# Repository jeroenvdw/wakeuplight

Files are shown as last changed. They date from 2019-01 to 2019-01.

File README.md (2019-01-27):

# Arduino Wake Up Light
## Features
 - a normal alarm (like any alarm clock)
 - a repeating alarm, which can be configured for every day of the week
 - it can function as a night lamp
 - choose the buzzer or any MP3 to wake up with
 - time is kept with a RTC (real time clock)
 - all settings (max light intensity, wake up duration, ...) can be configured within the menu
 - when power is switched off and on again, the date, time and other settings are restored

## Parts list
 - Arduino Uno
 - RTC (I used the DS3231 for a Raspberry Pi because of the small form factor)
 - LCD; 16x2 characters, with I²C interface
 - Buzzer
 - MP3 module (I used the DFRobot DFPlayer)
 - Speaker 
 - LED strtip (12 volt)
 - NPN Transistor (I used TIP-120)
 - 7 push buttons (for Left, Right, Up, Down, OK, Cancel, Snooze)
 - 9 resistors 1K Ohm (7 pull down resistors, one for the MP3 module, one for the transistor)
 - 12 Volt power supply
 - Wires, Male/Female headers, Perfboard, ... (to solder everything together)
 
 ## The build
 The schematic to solder everything together can be found in "schematic.pdf" (schematic.fzz is the original Fritzing file)
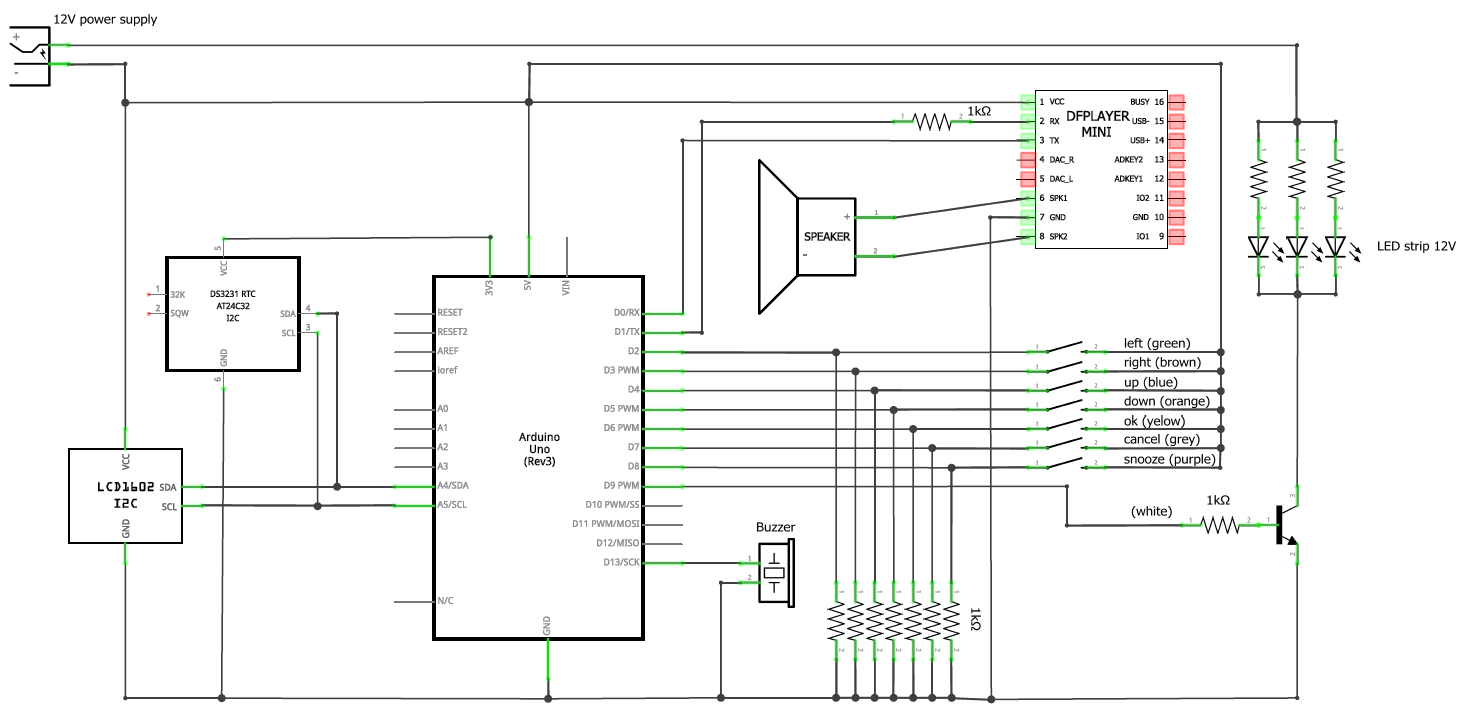
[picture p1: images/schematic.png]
 
 
 ## The code
 For a better understanding of the lifecycle of the alarm, have a look at "lifecycle.pdf". 
 To undesttand the menu structure, check out "screenflow.pdf" (source files are in the \*.dia files)
 
 All literals in the menu are now in Dutch. Rename the "Literals_EN.h" file to "Literals.h" to build the proejct using English literals.
 
 ## Images
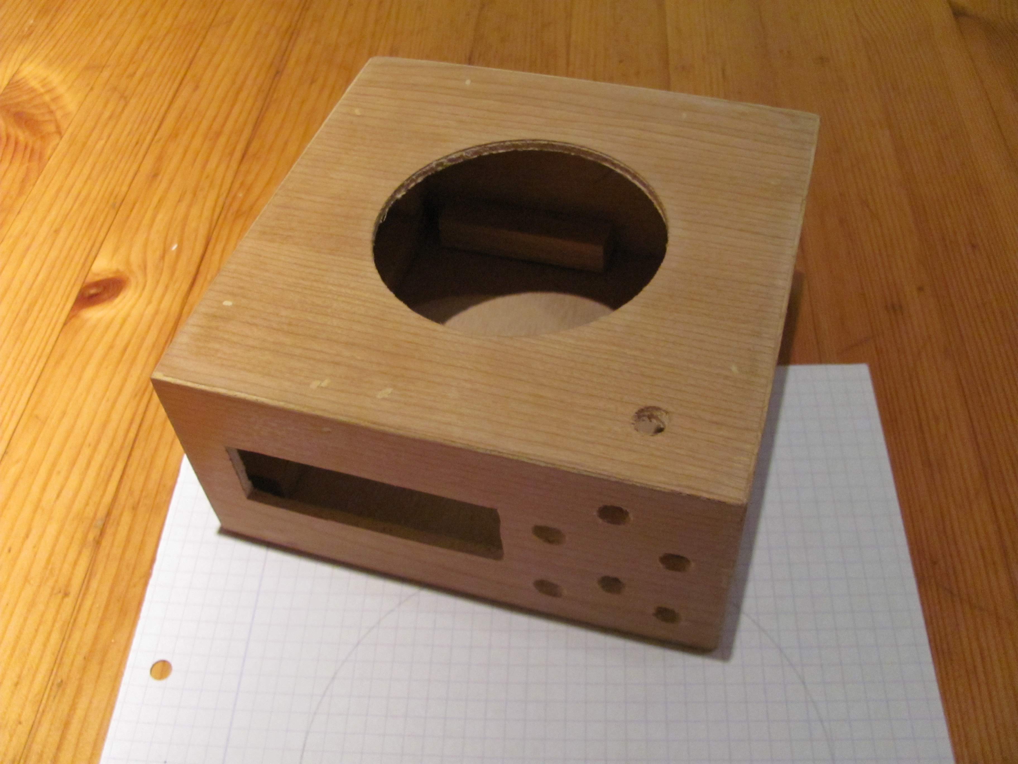
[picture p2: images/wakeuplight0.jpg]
 
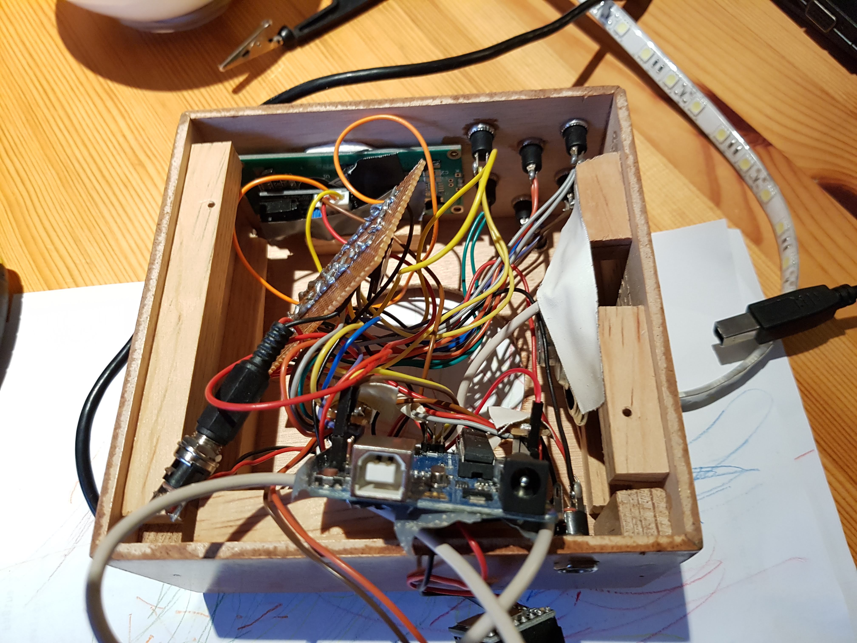
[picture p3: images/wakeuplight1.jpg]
 
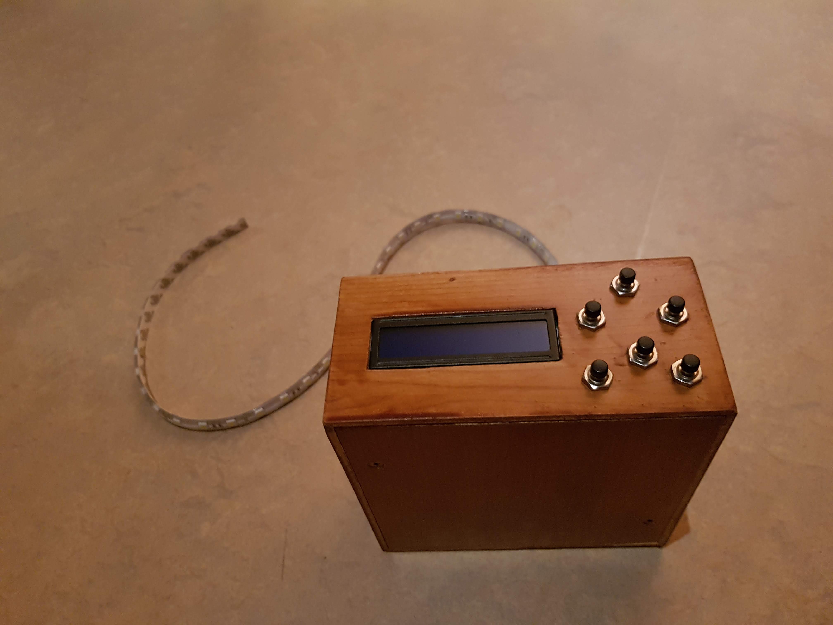
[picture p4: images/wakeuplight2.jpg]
 
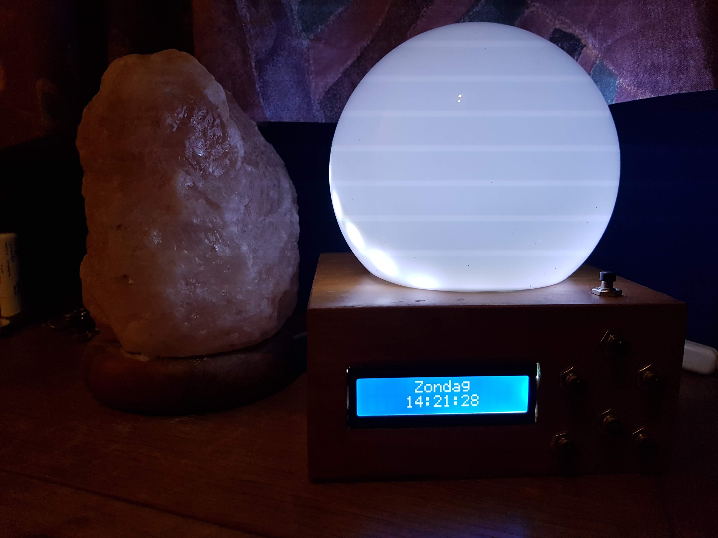
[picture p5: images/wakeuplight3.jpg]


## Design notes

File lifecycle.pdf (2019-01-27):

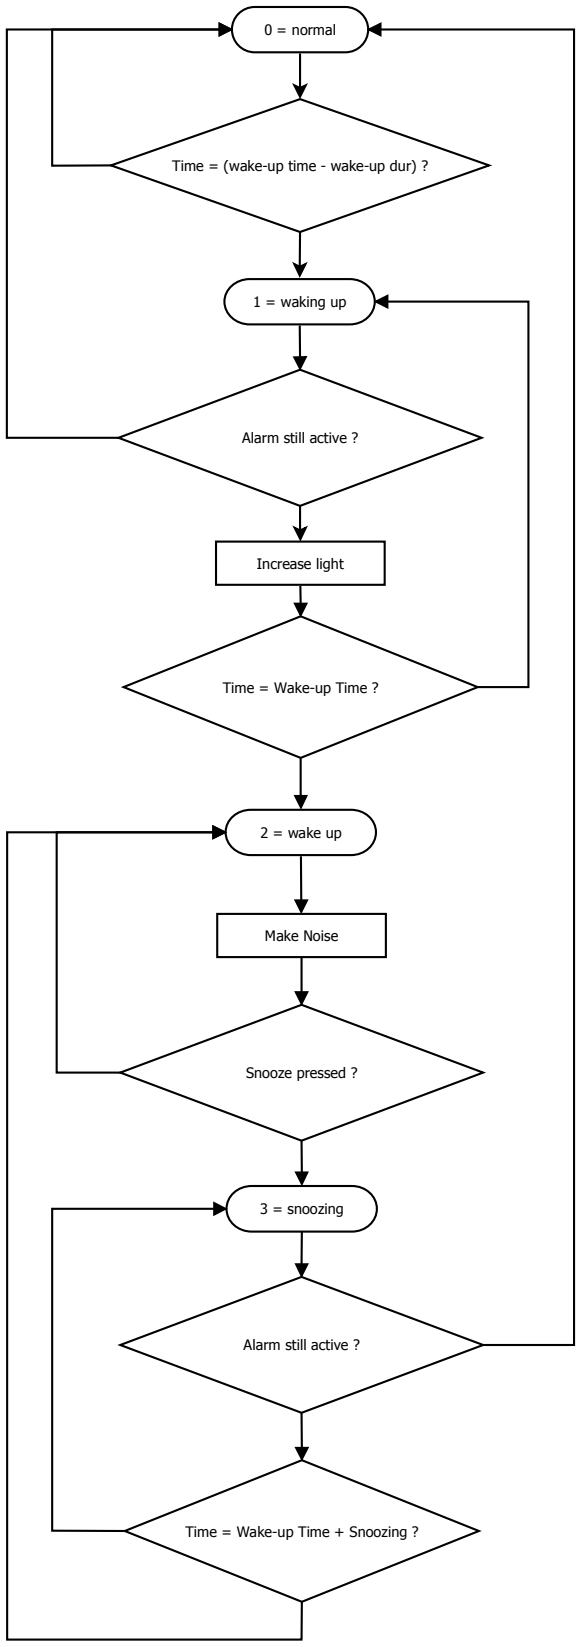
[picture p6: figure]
0 = normal; Time =; (wake-up time - wake-up dur) ?; 1 = waking up; Alarm still active ?; Increase light; Time = Wake-up Time ?; 2 = wake up; Make; Noise; 3 = snoozing; Time = Wake-up; Time + Snoozing ?; Snooze pressed ?

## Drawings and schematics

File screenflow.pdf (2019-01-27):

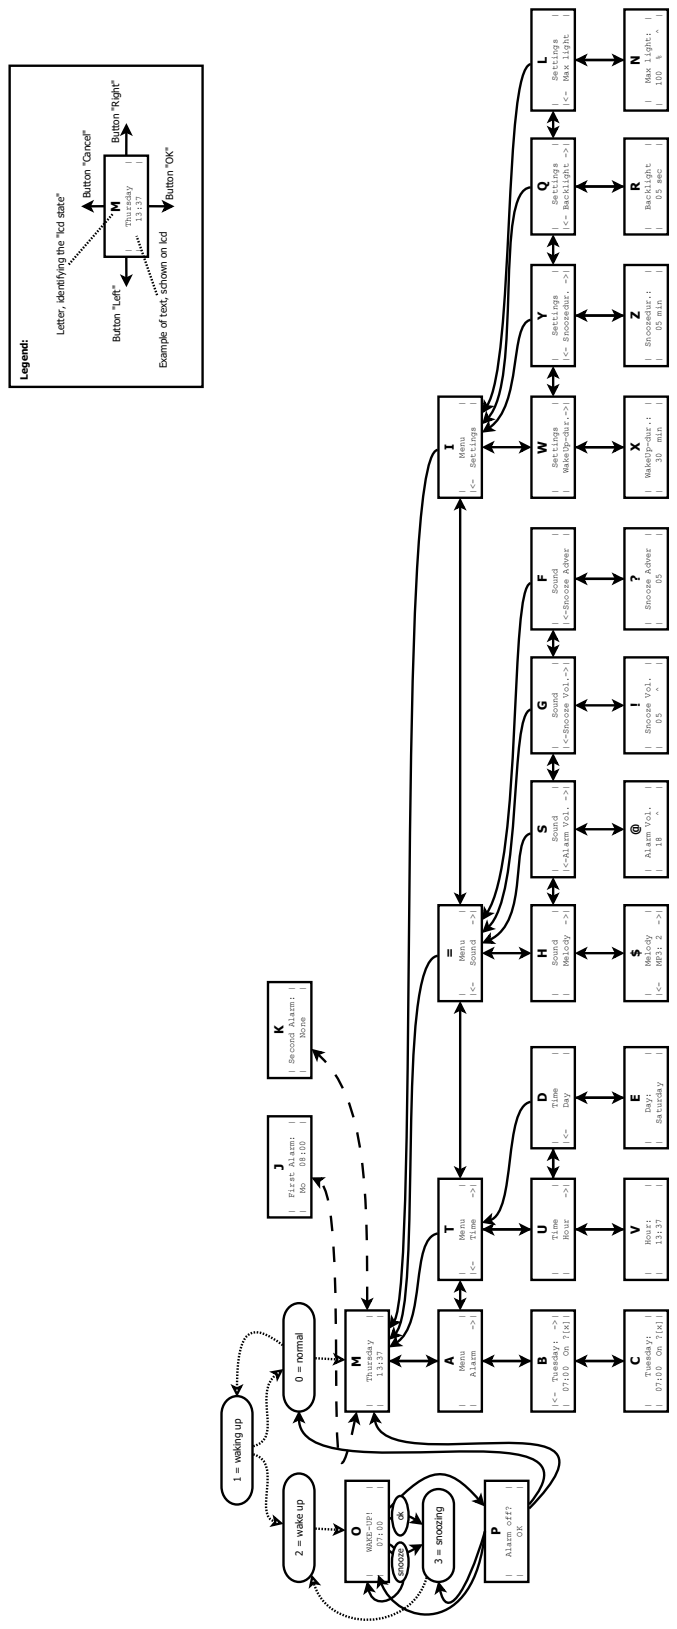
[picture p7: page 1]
| Thursday |; | Menu |; | Alarm ->|; |<- Settings |; |<- Time ->|; | Settings |; | WakeUp-dur.->|; |<- Max light |; | WakeUp-dur.: |; | 30 min |; | Max light: |; | Hour: |; | Tuesday: |; |<- Tuesday: ->|; | Time |; | Hour ->|; |<- Day |; | Day: |; | Saturday |; | WAKE-UP! |; | Alarm off? |; 0 = normal; 1 = waking up; 2 = wake up; | Sound |; |<-Snooze Adver |; | Snooze Adver |; |<- Snoozedur. ->|; | Snoozedur.: |; | 05 min |; 3 = snoozing; ok snooze; | First Alarm: |; | Second Alarm: |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

Button "Left" Button "Right"

Letter, identifying the "lcd state"

Example of text, schown on lcd

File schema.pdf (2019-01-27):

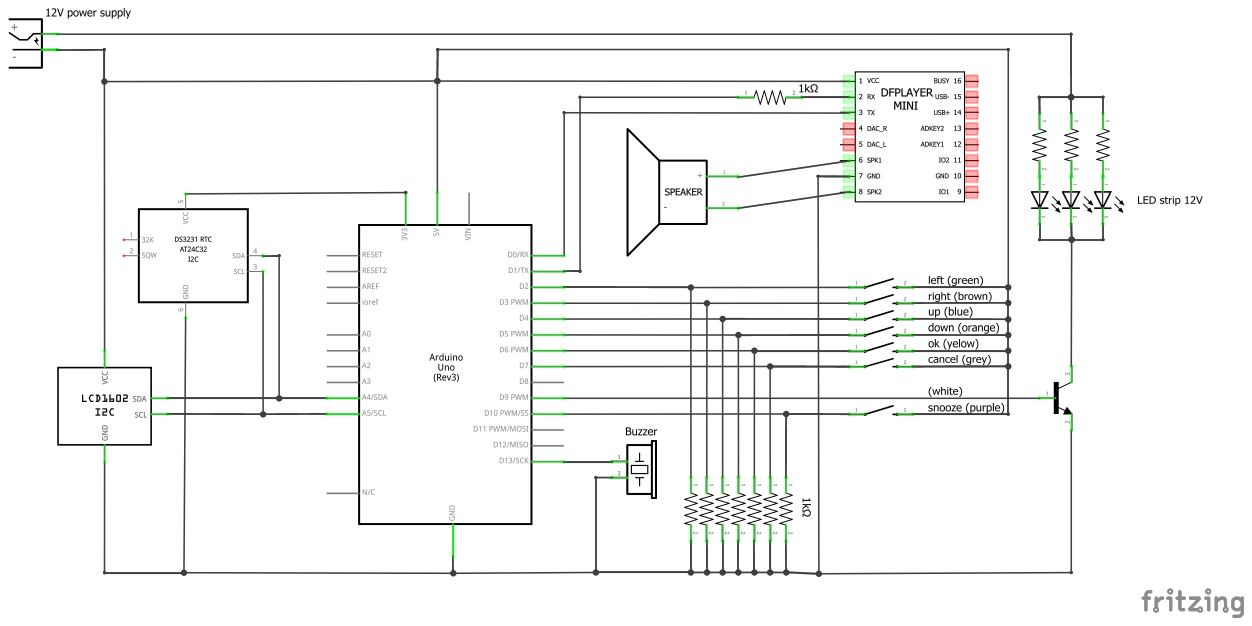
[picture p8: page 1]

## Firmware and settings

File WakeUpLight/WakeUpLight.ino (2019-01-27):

#include <LiquidCrystal_I2C.h>    // https://github.com/fdebrabander/Arduino-LiquidCrystal-I2C-library
#include <Bounce2.h>              // https://github.com/thomasfredericks/Bounce2
#include <DFRobotDFPlayerMini.h>  // https://github.com/DFRobot/DFRobotDFPlayerMini
#include <ds3231.h>               // https://github.com/rodan/ds3231
#include <SoftwareSerial.h>
#include <Wire.h>
#include "Time.h"
#include "AlarmController.h"
#include "AlarmSettings.h"
#include "Alarm.h"
#include "WeekAlarm.h"
#include "MP3Player.h"


const uint8_t snoozePin = 12;   //Purple 
const uint8_t leftPin = 2;      //Green
const uint8_t rightPin = 3;     //Brown
const uint8_t upPin = 4;        //Blue
const uint8_t downPin = 5;      //Orange
const uint8_t okPin = 6;        //Yellow
const uint8_t cancelPin = 7;    //Grey
const uint8_t ledPin = 9;       //White

const uint8_t RXPin = 0;
const uint8_t TXPin = 1;
const uint8_t buzzerPin = 13;

const uint8_t bounceDelay = 6;

double fadeValue = 0.0;
unsigned long timeStart = 0;
unsigned long timeHigh = 0;
unsigned long timeOn = 0;
unsigned long timeOnPrev = 0;

SoftwareSerial swSerial(RXPin, TXPin); 
DFRobotDFPlayerMini dfPlayer;
MP3Player mp3(&swSerial,&dfPlayer);

AlarmSettings set;
LiquidCrystal_I2C lcd(0x27,16,2); 
AlarmController ac(&set,&lcd,&mp3,ledPin,buzzerPin);

Bounce btnLeft = Bounce();
Bounce btnRight = Bounce();
Bounce btnUp = Bounce();
Bounce btnDown = Bounce();
Bounce btnOK = Bounce();
Bounce btnCancel = Bounce();
Bounce btnSnooze = Bounce();

uint8_t lastUpdateHour = 0;


void setup()  { 
  ac.initializeLCD();
  ac.initializeMP3();
  DS3231_init(DS3231_CONTROL_INTCN);
  set.updateTimeFromRTC();
  set.loadFromEEPROM();
  
  pinMode(ledPin, OUTPUT);
  pinMode(buzzerPin, OUTPUT);
  pinMode(leftPin, INPUT);
  pinMode(rightPin, INPUT);
  pinMode(upPin, INPUT);
  pinMode(downPin, INPUT);
  pinMode(okPin, INPUT);
  pinMode(cancelPin, INPUT);
  pinMode(snoozePin, INPUT);
  btnLeft.attach(leftPin);
  btnLeft.interval(bounceDelay);
  btnRight.attach(rightPin);
  btnRight.interval(bounceDelay);
  btnUp.attach(upPin);
  btnUp.interval(bounceDelay);
  btnDown.attach(downPin);
  btnDown.interval(bounceDelay);
  btnOK.attach(okPin);
  btnOK.interval(bounceDelay);
  btnCancel.attach(cancelPin);
  btnCancel.interval(bounceDelay);
  btnSnooze.attach(snoozePin);
  btnSnooze.interval(bounceDelay);
  
  timeStart = millis();
  timeOn = millis();
  timeOnPrev = timeOn;

  digitalWrite(buzzerPin, LOW);
  analogWrite(ledPin, 0);

  ac.setMakeLight(analogWrite);
} 

void loop()  { 
  //update time
  timeOn = millis();
  if(timeOn<timeOnPrev) { //overflow!!
    set.getTime()->addMillis((4294967295ul - timeOnPrev) + timeOn);
  }
  else{
    set.getTime()->addMillis(timeOn - timeOnPrev);
  }
  timeOnPrev = timeOn;
  //every 12 hours (at 4:30 and 16:30), update the time from RTC
  if((set.getTime()->getHour() == 4 || set.getTime()->getHour() == 16) && (set.getTime()->getMin() == 30)) {
    if(lastUpdateHour != set.getTime()->getHour())  {
      set.updateTimeFromRTC();
      lastUpdateHour = set.getTime()->getHour();
    }
  }
  
  //update AlarmState
  ac.checkAlarmState();  
  
  //update LCD
  ac.printLCD();

  //check snooze-button
  btnSnooze.update();
  if(btnSnooze.risingEdge()) {
    ac.doSnooze();
    if(ac.getAlarmState() == 0) {
      timeStart = millis();
      btnSnooze.update();
      ac.printLCD();
      fadeValue = 0.0;
      analogWrite(ledPin,round(fadeValue));
      while(btnSnooze.read() == HIGH) {
        if(abs(millis() - timeStart) > 600) {
          fadeValue += 0.5;
          if(fadeValue > 255) {
            fadeValue = 255.0;
          }
          analogWrite(ledPin,round(fadeValue));
          delay(10);
        }
        btnSnooze.update();
      }
    }
  }

  //Check other buttons
  btnLeft.update();
  btnRight.update();
  btnUp.update();
  btnDown.update();
  btnOK.update();
  btnCancel.update();

  if(btnOK.risingEdge()) {
    ac.doOK();
  }
  else if(btnCancel.risingEdge()) {
    ac.doCancel(); 
  }
  else if(btnLeft.risingEdge()) {
    ac.doLeft();
  }
  else if(btnLeft.fallingEdge()) {
    ac.endLeft();
  }
  else if(btnRight.risingEdge()) {
    ac.doRight();
  }
  else if(btnRight.fallingEdge()) {
    ac.endRight(); 
  }
  else if(btnUp.risingEdge()) {
    ac.doUp();
    btnUp.update();
    timeStart = millis();
    ac.printLCD();
    while(btnUp.read() == HIGH) {
      if(abs(millis() - timeStart) > 800) {
        ac.doUp();
        ac.printLCD();
        delay(140);
      }
      btnUp.update();
    }
  }
  else if(btnDown.risingEdge()) {
    ac.doDown();
    btnUp.update();
    timeStart = millis();
    ac.printLCD();
    while(btnDown.read() == HIGH) {
      if(abs(millis() - timeStart) > 800) {
        ac.doDown();
        ac.printLCD();
        delay(140);
      }
      btnDown.update();
    }
  }
  
}

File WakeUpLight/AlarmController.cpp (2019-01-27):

/*************************
 ** AlarmController.cpp
 ************************/

#include "AlarmController.h"
#include "Literals.h"
#include <avr/pgmspace.h>
using namespace AlarmLiterals;

const char SPACE = ' ';
const char COLON = ':';
const char ZERO = '0';
const char* LEFT = "<-";
const char* RIGHT = "->";
const char SPACE2[] = {SPACE,SPACE,'\0'};
const char* EMPTY = "";

const uint8_t LEDOFF = 0;
const uint8_t LEDON = 1;
const uint8_t SPEAKEROFF = 2;
const uint8_t SPEAKERON = 3;
const uint8_t NEXTSONG = 4;

unsigned long buzzerStart = 0;
// buzzer pattern       x        x        x        x        x      x        x      x        x      x      x        x      x      x        x      x      x      x        x      x      x      x        x      x      x      x      x        x      x      x      x      x
const int buzzerP[] = {150,2000,150,2000,150,2000,150,2000,150,80,150,2000,150,80,150,2000,150,80,150,80,150,2000,150,80,150,80,150,2000,150,80,150,80,150,80,150,2000,150,80,150,80,150,80,150,2000,150,80,150,80,150,80,150,80,150,2000,150,80,150,80,150,80,150,80,150,1000};
const int buzzerPL = 64; //buzzer pattern length
const uint8_t buzzerL = 54; //buzzer loop
int buzzerPI = 0; //buzzer pattern index


AlarmController::AlarmController(AlarmSettings* settings, LiquidCrystal_I2C* lcd,MP3Player* mp3, uint8_t ledPin, uint8_t buzzerPin) {
  _lcd = lcd;
  _mp3 = mp3;
  _settings = settings;
  _lcdState = 'M';
  _makeLight = NULL;
  _ledPin = ledPin;
  _buzzerPin = buzzerPin;
  _playBuzzer = false;
  _activeAlarm = 8;
  _backlightOn = true;
  _buttonPressedSec = _settings->getTime()->getSec();
}

void AlarmController::initializeLCD() {
  _lcd->begin();  
  _lcd->setBacklight(1);
  _lcd->home();
  _lcd->setCursor(0,0);
  _lcd->print(F("setup lcd"));
  
  uint8_t ledOff[8] = { 0b00000,
                        0b00000,
                        0b00000,
                        0b00000,
                        0b00100,
                        0b01110,
                        0b01110,
                        0b01110 };
  uint8_t ledOn[8] = { 0b00100,
                       0b10101,
                       0b10101,
                       0b00000,
                       0b00100,
                       0b01110,
                       0b01110,
                       0b01110 };

  _lcd->createChar(LEDOFF, ledOff);
  _lcd->createChar(LEDON, ledOn);

  uint8_t speakerOff[8] = { 0b00100,
                            0b01100,
                            0b11100,
                            0b11100,
                            0b11100,
                            0b11100,
                            0b01100,
                            0b00100 };
  uint8_t speakerOn[8] = { 0b00101,
                           0b01101,
                           0b11100,
                           0b11101,
                           0b11101,
                           0b11100,
                           0b01101,
                           0b00101 };

  uint8_t nextSong[8] = { 0b00100,
                          0b01110,
                          0b10101,
                          0b00100,
                          0b00100,
                          0b00100,
                          0b00100,
                          0b00100 };

  _lcd->createChar(SPEAKEROFF, speakerOff);
  _lcd->createChar(SPEAKERON, speakerOn);
  _lcd->createChar(NEXTSONG, nextSong);
}

void AlarmController::initializeMP3() {
  _lcd->setCursor(0,0);
  _lcd->print(F("setup mp3"));
  _mp3->initialize();
  _mp3->setVolume(_settings->getAlarmVolume());
}


void AlarmController::printString(char* string, char* sleft, char* sright) {
  //strcpy_P(buffer, (char*)pgm_read_word(&(string)));
  int len = strlen(string);
  int spaces = 16 - len - strlen(sleft) - strlen(sright);
  _lcd->print(sleft);
  for(int i=0; i<spaces/2; i++) {
    _lcd->print(SPACE);
  }
  _lcd->print(string);
  for(int i=0; i<spaces/2+spaces%2; i++) {
    _lcd->print(SPACE);
  }
  _lcd->print(sright);
}

void AlarmController::printString(char* string) {
  printString(string,EMPTY,EMPTY);
}

void AlarmController::printLCD() {
  controlBacklight();
  if(_lcdState == 'M') {
    printMainScreen();
  } else if(_lcdState == 'A') {
    printMenuA();
  } else if(_lcdState == 'B') {
    printAlarmMenu();
  } else if(_lcdState == 'C') {
    printSetAlarm();
  } else if(_lcdState == 'T') {
    printMenuT();
  } else if(_lcdState == 'U') {
    printMenuU();
  } else if(_lcdState == 'D') {
    printMenuD();
  } else if(_lcdState == 'V') {
    printSetHour();
  } else if(_lcdState == 'E') {
    printSetDay();
  } else if(_lcdState == 'I') {
    printMenuI();
  } else if(_lcdState == 'W') {
    printMenuW();
  } else if(_lcdState == 'L') {
    printMenuL();
  } else if(_lcdState == 'X') {
    printSetWakeUpDur();
  } else if(_lcdState == 'N') {
    printSetWakeUpLum();
  } else if(_lcdState == 'O') {
    printWakeUp();
  } else if(_lcdState == 'P') {
    printTurnOffAlarm();
  } else if(_lcdState == 'J') {
    print1stAlarm();
  } else if(_lcdState == 'K') {
    print2ndAlarm();
  } else if(_lcdState == 'Y') {
    printMenuY();
  } else if(_lcdState == 'Z') {
    printSetSnooze();
  } else if(_lcdState == 'Q') {
    printMenuQ();
  } else if(_lcdState == 'R') {
    printSetBacklight();
  } else if(_lcdState == 'F') {
    printMenuF();
  } else if(_lcdState == '?') {
    printSetSnoozeAdvert();
  } else if(_lcdState == 'H') {
    printMenuH();
  } else if(_lcdState == '$') {
    printSetSound();
  } else if(_lcdState == 'S') {
    printMenuS();
  } else if(_lcdState == '@') {
    printSetAlarmVolume();
  } else if(_lcdState == '!') {
    printSetSnoozeVolume();
  } else if(_lcdState == '=') {
    printMenuEqual();
  } else if(_lcdState == 'G') {
    printMenuG();
  }
  controlBacklight();
}
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
